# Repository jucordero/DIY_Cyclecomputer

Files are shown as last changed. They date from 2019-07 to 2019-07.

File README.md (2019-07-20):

# DIY Cyclecomputer

Custom made cycle computer / GPS tracker based on the Adafruit Feather Adalogger M0, East Rising ERC240120 240 x 120 pixel monochrome Graphical LCD display, and the Quectel L80-R Serial GPS tracker.

This repository contains everything needed to create a GPS tracker:
- CAD files for the enclosure
- Schematics for the electronics including bill of materials
- Firmware to flash the microcontroller

Electronics were designed using Kicad. __Electronics__ folder contains the KiCAD schematic and board footprint to creathe the main PCB along with the required components to populate it. I'm also including all the libraries used for the not standard parts (GPS, 23-pin screen FPC cable socket, Feather M0, etc.).  
The case was designed using Fusion 360. __Case__ includes the .STEP files for the case, which can be 3D printed in 5 different pieces with minimal support material required. From the .STEP files it should be easy to modify the dimensions to fit different modifications of the design.  
Firmware developed using Arduino. __Firmware__ contains the required .ino files to flash the firmware to the microcontroller. It is based on the Feather Adalogger M0 (ATSAMD21G18 ARM Cortex M0 processor) and can be flashed using either the Arduino IDE or the PlatformIO extension to Atom. The power-on circuit is based on the ATTINY85 and it is intended to provide both powering and control functions.

A few renders and finished prototype

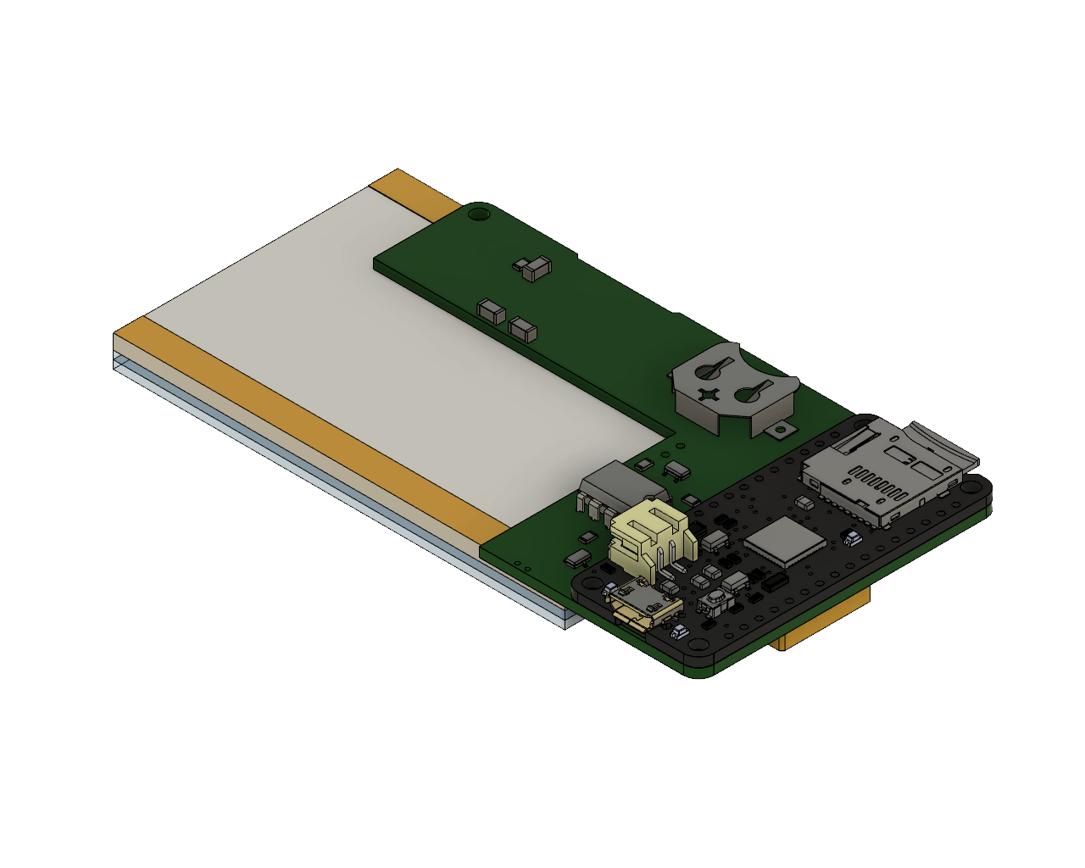
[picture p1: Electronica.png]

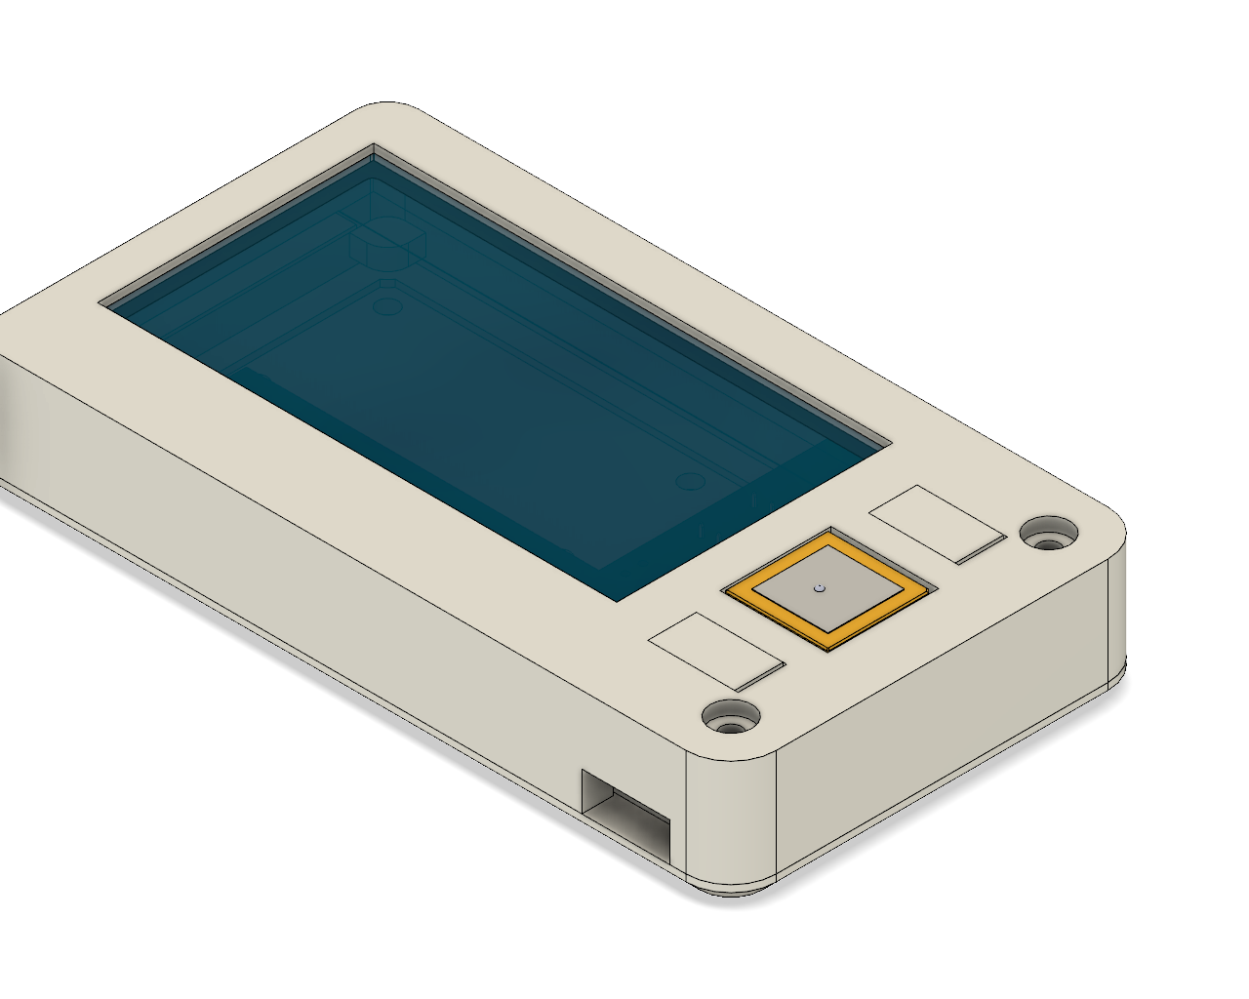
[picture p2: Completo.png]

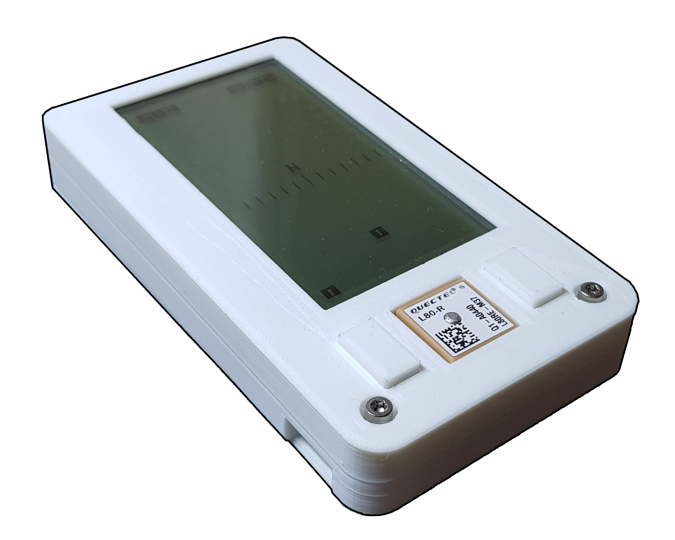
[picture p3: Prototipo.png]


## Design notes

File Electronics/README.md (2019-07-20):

# Electronics

The microcontroller board used is the Adafruit Feather Adalogger M0:
https://learn.adafruit.com/adafruit-feather-m0-adalogger/overview

While not the cheapest option, it provides both the form the factor and ease of integration to the project in terms of not having to bootload
a custom microcontroller chip. Also, having the SD card reader on board facilitates things a lot.
Of course there are plans to move to a completely integrated design, with a fully custom board including the SAM21G18 to drive the display and perfipherals.

The GPS module is the Quectel L80-R. a cheaper version of the L80, with excellent reliability and a reazonable price.
I get them from aliexpress.
The next step is to use the lower profile Quectel L70 plus a chip antenna (GPS1003), which can dramatically reduce the footprint of the main board.

Display module is the East Rising 240 x 120 monochrome LCD display
https://www.buydisplay.com/default/serial-spi-240x120-touch-panel-graphic-lcd-cog-display-connector-fpc
It uses a standard SPI interface and a not so standard 23-pin FPC connector with a 0.5 mm pitch.

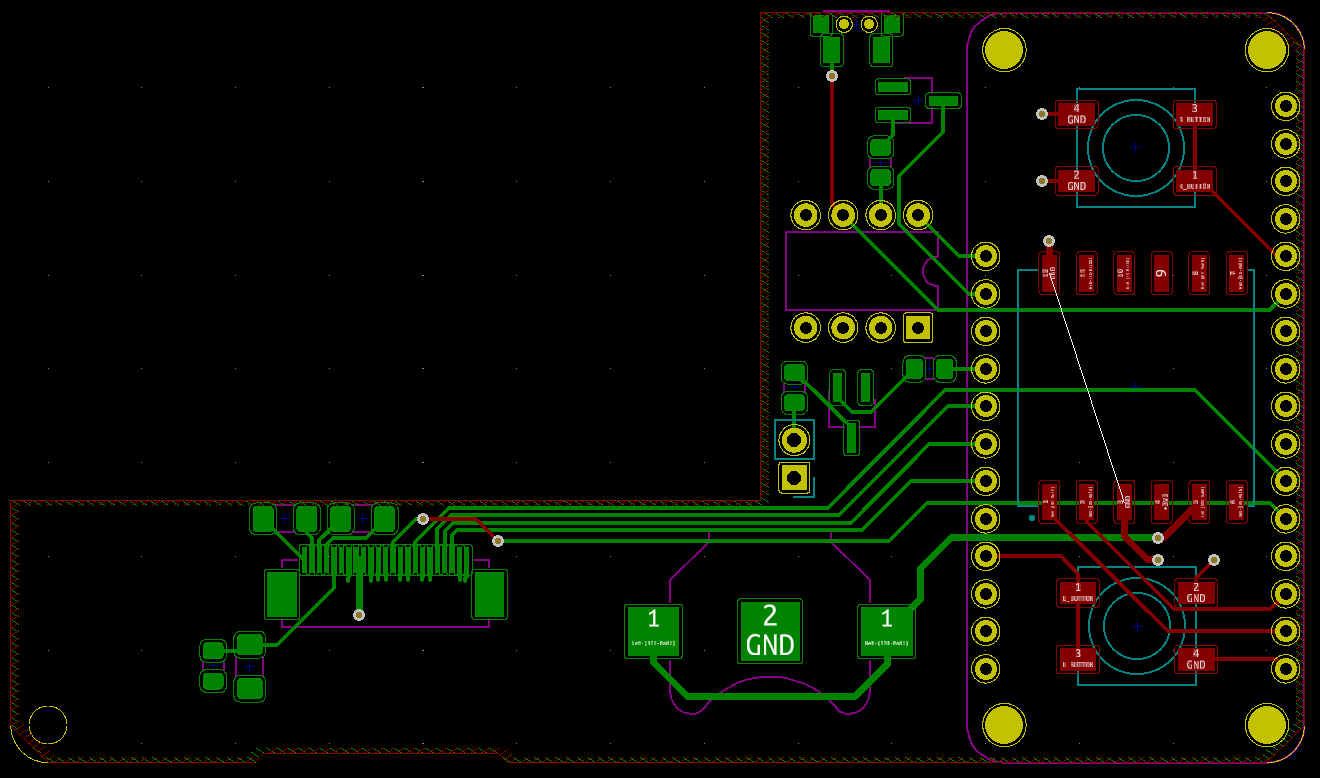
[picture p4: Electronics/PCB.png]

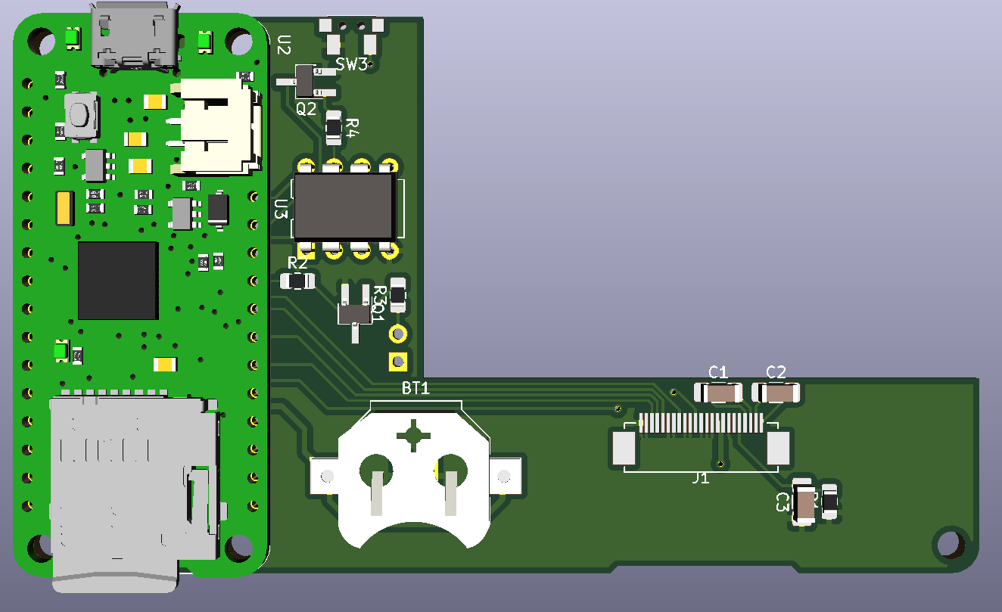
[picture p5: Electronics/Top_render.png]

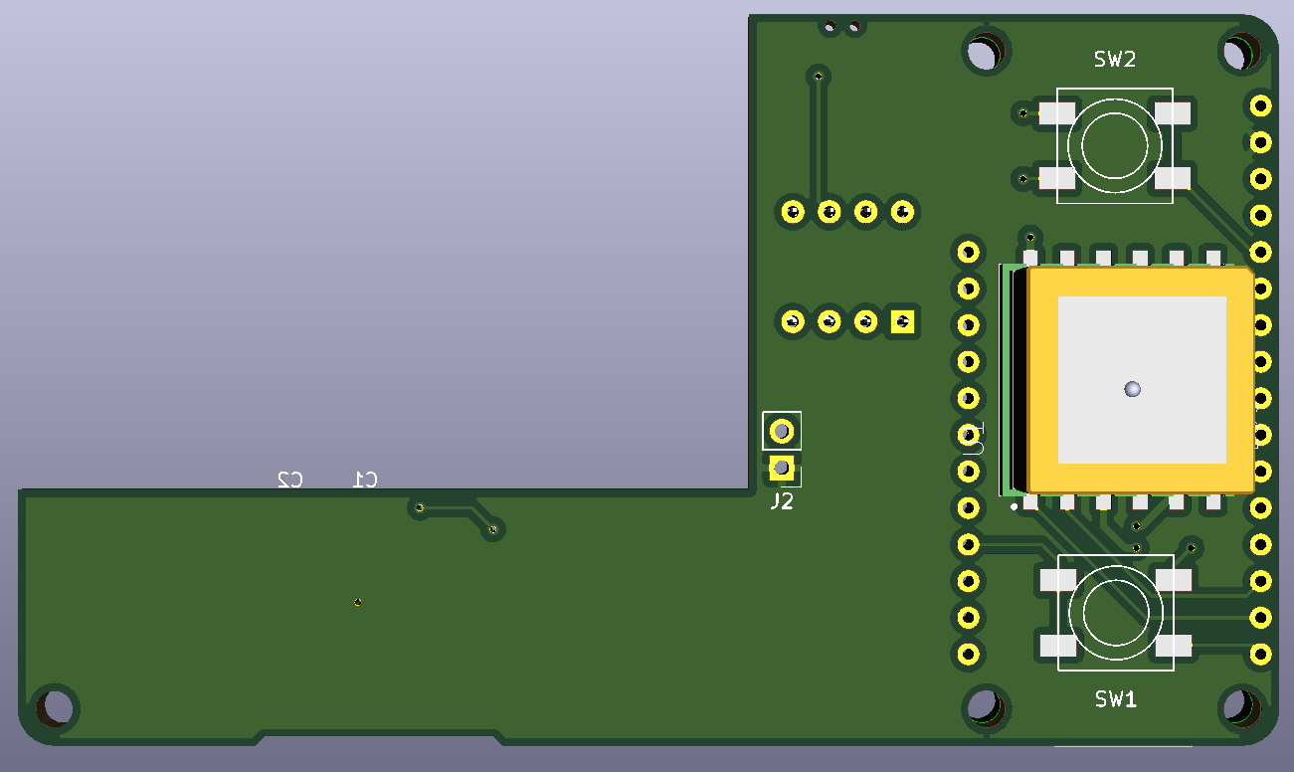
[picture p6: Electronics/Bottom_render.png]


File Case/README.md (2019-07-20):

# Case

The case was created using Fusion 360.
It is made up 5 bodies:

1. Main case
2. Back lid
3. Side button cap
4. Front left button cap
5. Front right button cap

The main PCB is held in place using M2.5 screws. A hex head 14 mm screw inserts from the front and attachs to two brass threaded inserts on the back lid.
Two plastic M2.5 6mm screws secure the top side of the back lid by attaching to two additional threaded inserts in the main case.
Threaded inserts are added to the case using a soldering iron.

The back lid has holes for 9 round 3x1mm neodynium magnets which are intended to be used as a mounting mechanism.
The magnets used are not very powerful so should be updating the design to either stronger magnets or a different mechanism.

The two front button caps are placed on top of two momentary rubber dome push buttons place either side of the GPS antenna.
The button on the side is a horizontal push button which is pressed by the side plastic button cap.

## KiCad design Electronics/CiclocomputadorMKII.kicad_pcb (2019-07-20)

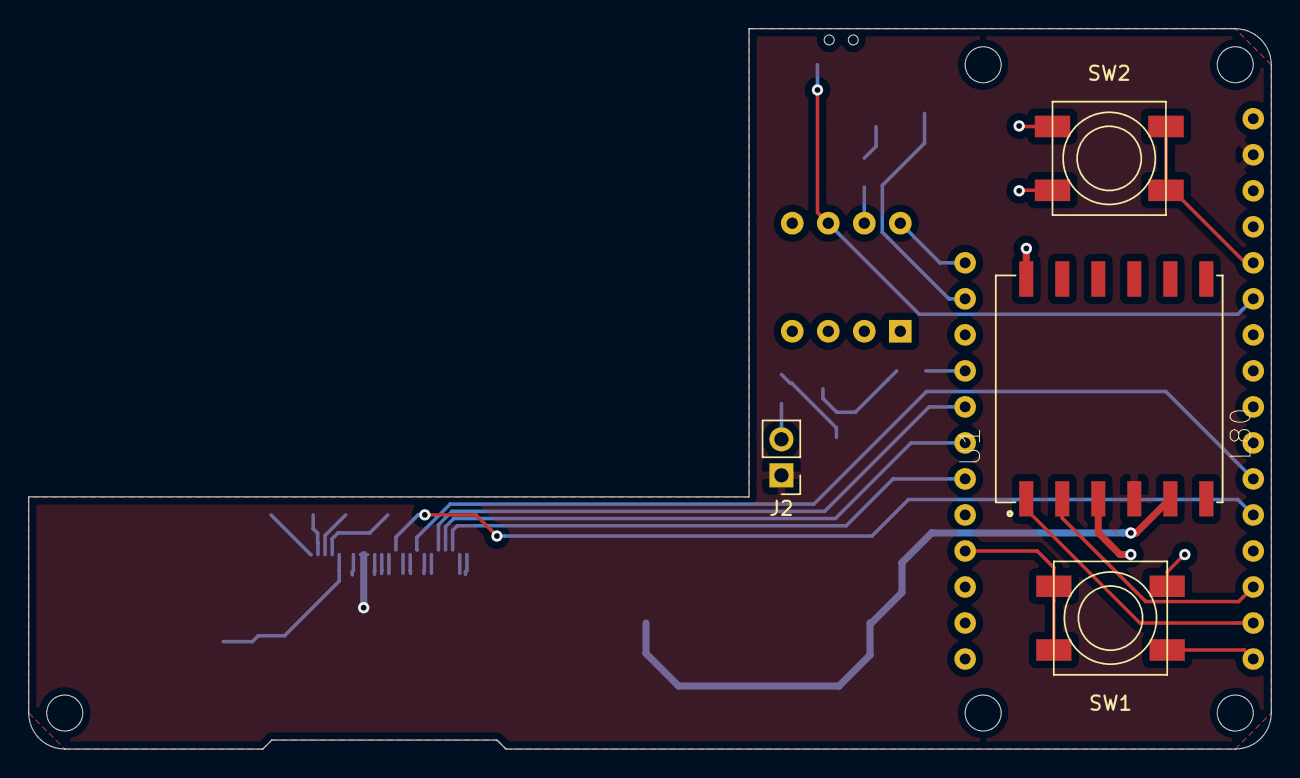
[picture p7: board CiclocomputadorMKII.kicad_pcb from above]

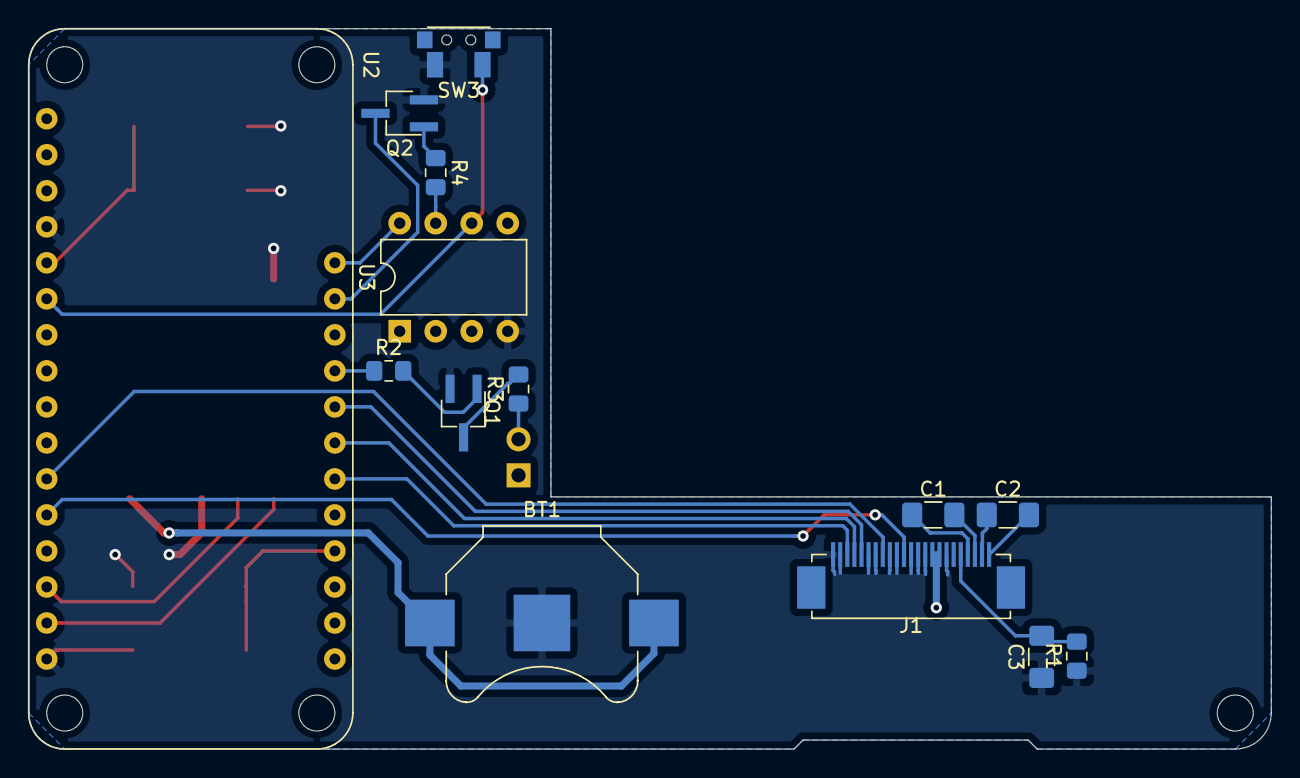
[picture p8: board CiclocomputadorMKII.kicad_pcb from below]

Board: 2 copper layers, 87.6 x 50.8 mm, 18 parts (14 on the bottom side), 26 nets.

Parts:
BT1: Battery_Cell; BatteryHolder_Keystone_3000_1x12mm
C1, C2, C3: C; C_1206_3216Metric_Pad1.42x1.75mm_HandSolder
J1: Conn_01x23; FPC_23C_0.5mm
J2: Conn_01x02_Male; PinHeader_1x02_P2.54mm_Vertical
Q1, Q2: Q_NPN_BEC; TSOT-23_HandSoldering
R1, R2, R3, R4: R; R_0805_2012Metric_Pad1.15x1.40mm_HandSolder
SW1, SW2: SW_Push_Dual; SW_DPST_Soft_8mm
SW3: SW_Push; 2x4x3.5mm SMD tactile switch
U1: L80; GPSMODULE_L80
U2: FeatherM0Adalogger; Adafruit_Feather_base
U3: ATtiny85V-10PU; DIP-8_W7.62mm

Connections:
+3V3: J1.15, J1.16, J2.1, U1.4, U2.2
CS: J1.3, U2.22
DC: J1.5, U2.24
EN: Q2.3, U2.27
GND: BT1.2, C3.1, J1.1, J1.2, J1.6, J1.7, J1.9, J1.10, J1.12, J1.13, J1.14, J1.17, Q1.2, Q2.2, R1.1, SW1.2, SW1.4, SW2.2, SW2.4, SW3.1, U1.3, U1.12, U2.4, U2.16, U3.4
LEDPIN: R2.1, U2.25
L_BUTTON: SW1.1, SW1.3, U2.20
MOSI: J1.11, U2.12
unnamed: BT1.1, U1.5
unnamed: C1.1, J1.20
unnamed: C1.2, J1.21
unnamed: C2.1, J1.22
unnamed: C2.2, J1.23
unnamed: C3.2, J1.19, R1.2
unnamed: J2.2, R3.1
unnamed: Q1.1, R2.2
unnamed: Q1.3, R3.2
unnamed: Q2.1, R4.1
unnamed: R4.2, U3.7
unnamed: U1.1, U2.15
unnamed: U1.2, U2.14
RESET: J1.4, U2.23
R_BUTTON: SW2.1, SW2.3, U2.5
SCK: J1.8, U2.11
SIDE_BUTTON: SW3.2, U2.6, U3.6
VBAT: U2.28, U3.8
